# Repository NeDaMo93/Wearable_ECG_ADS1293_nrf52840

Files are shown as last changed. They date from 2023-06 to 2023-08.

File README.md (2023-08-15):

# Wearable_ECG_ADS1293_nrf52840
Software for a Functional Demonstrator of a Medical Wearable for ECG and Activity Monitoring with Wireless Communication. With ADS1293, nrf52840, LSM6DSO. Includes an Android App and Python GUI.
# Summary of the research project
This research project aims to design and develop a functional demonstrator of a portable device for long-term Electrocardiogram (ECG) measurements. The proposed device intends to address the need for continuous and non-invasive monitoring of cardiac activity over extended periods, providing valuable insights into the diagnosis and management of cardiovascular conditions.
In addition to enabling long-term Electrocardiogram (ECG) measurements, the developed wearable device will also incorporate advanced sensors to monitor body position, physical activity, and body temperature continuously. This comprehensive approach aims to provide a holistic assessment of the user's physiological status, allowing for a more thorough evaluation of their overall health. 
The primary objective of this project is to create a working prototype that can serve as a foundation for future advancements in the field. The successful development of this device will facilitate subsequent research projects, fostering innovation and further exploration of long-term ECG monitoring technologies at our institution.
Throughout the research process, various aspects, such as hardware design, signal processing algorithms, power efficiency, and user-friendliness, will be carefully considered and optimized to ensure the device's reliability and practicality. Additionally, emphasis will be placed on achieving a cost-effective solution without compromising the quality of data collected.
Ultimately, the successful completion of this project will lay the groundwork for subsequent investigations, encouraging a continuous cycle of research and development in the domain of portable long-term ECG monitoring. The findings and insights gained from this study will contribute significantly to the improvement of cardiac healthcare and enhance the quality of life for individuals with cardiovascular conditions.
# Hardware Architecture
Based on the requirements, the concept architecture and associated functions could be defined by using specific hardware, which is shown in the following figure. For the demonstrator, Nordic's nRF52840 microcontroller acts as the central element, which is available in the form of a developer board from Adafruit Feather. This board has several integrated functions, including push buttons for triggering external events, LEDs for status indication, and an energy-efficient Bluetooth module. A matching SD card module from Adafruit allows local storage of recorded data. The ADS1293 is used as the analog front end for processing ECG signals. The user's activity level and body position are detected with the help of the ST LSM6DSO IMU. Body temperature is measured by using a PT1000 sensor. The Easypack S rechargeable battery system from Varta supplies the necessary energy. Finally, the collected data is transmitted via Bluetooth to a PC and Android smartphone and displayed.

# Software Architecture
The firmware is designed to efficiently handle data acquisition from the ECG and IMU (Inertial Measurement Unit) sensors and transmit the collected data via Bluetooth Low Energy (BLE) while storing it on an SD card. The architecture is implemented using six components, including four separate threads and two interrupt Service Routines (ISRs).

# User Interfaces
## Anrdoid App
The Android application was constructed using the open-source code provided by Nordic for the Android-nRF-Blinky application. 
The Android-nRF-Blinky application, written in Kotlin, serves as an excellent introduction for developers unfamiliar with Bluetooth Low Energy (BLE) and can serve as a template for other projects.
The application uses the Android BLE Library to manage its Bluetooth connections. When the application starts, it scans for nearby BLE devices. Once a device is selected, the application connects to it and discovers its services and characteristics (using the GATT protocol). 

## Python GUI
The Python-based graphical user interface (GUI) connects the ECG device via Bluetooth Low Energy (BLE) and visualizes real-time ECG data. It also displays the patient's activity level, body temperature, heart rate and body posture. The code utilizes PyQt5 for GUI development, Matplotlib for plotting, asyncio for asynchronous tasks, Bleak for BLE communication, and biosppy for ECG signal processing.


# LBS Files
lbs.h and lbs.c must be replaced in your zephyr directory <br>
**lbs.h:**<br>
..\nrf\include\bluetooth\services<br>
**lbs.c:**<br>
..\nrf\subsys\bluetooth\services<br>

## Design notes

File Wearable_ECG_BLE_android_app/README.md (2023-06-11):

# nRF Blinky for Android

nRF Blinky is an application targeting an audience of developers who are new to 
Bluetooth Low Energy. 

The app can be easily converted to work with other devices and may act as a template app.

This very simple application contains two basic features:
* turning on a LED on a connected Bluetooth LE device,
* receiving a Button press and release events from the device.

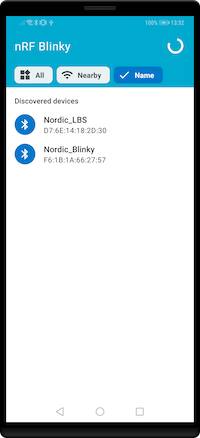
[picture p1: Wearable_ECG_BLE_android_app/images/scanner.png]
Scanner
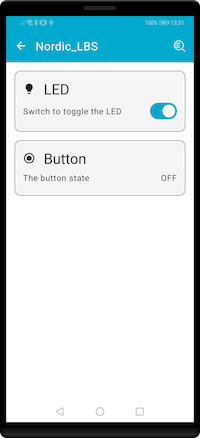
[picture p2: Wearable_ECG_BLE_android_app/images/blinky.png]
Blinky
 

It demonstrates how the `BleManager` class from 
[Android BLE Library](https://github.com/NordicSemiconductor/Android-BLE-Library/) 
library can be used from a View Model 
(see [Architecture Components](https://developer.android.com/topic/libraries/architecture/index.html)).

## Structure

The new version of nRF Blinky application has been created in Jetpack Compose.

### Dependencies

It is using the following libraries:
* [Android BLE Library](https://github.com/NordicSemiconductor/Android-BLE-Library/) - handles Bluetooth LE connectivity
* [Nordic Common Library for Android](https://github.com/NordicPlayground/Android-Common-Libraries) - theme and common UI components, e.g. scanner screen
* [nRF Logger tree for Timber](https://github.com/NordicSemiconductor/nRF-Logger-API) - logs to nRF Logger app using [Timber](https://github.com/JakeWharton/timber)
* [Android Gradle Plugins](https://github.com/NordicSemiconductor/Android-Gradle-Plugins) - set of Gradle plugins

The gradle script was written in Kotlin Script (*gradle.kts*) and is using version catalog for 
dependency management.

### Modules

The application consists of the following modules:

* **:app** - the main module, contains the application code
* **:scanner** - contains the scanner screen destination
* **:blinky:spec** - contains the Blinky device specification, e.g. [`Blinky`](https://github.com/NordicSemiconductor/Android-nRF-Blinky/blob/b23b0252fe14bd0961c1edafa973f7da2768feb9/blinky/spec/src/main/java/no/nordicsemi/android/blinky/spec/B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) API or the Service UUID
* **:blinky:ble** - contains the BLE related code, e.g. [`BlinkyManager`](https://github.com/NordicSemiconductor/Android-nRF-Blinky/blob/b23b0252fe14bd0961c1edafa973f7da2768feb9/blinky/ble/src/main/java/no/nordicsemi/android/blinky/ble/Bli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) implementation
* **:blinky:ui** - contains the UI related code, e.g. [`BlinkyScreen`](https://github.com/NordicSemiconductor/Android-nRF-Blinky/blob/b23b0252fe14bd0961c1edafa973f7da2768feb9/blinky/ui/src/main/java/no/nordicsemi/android/blinky/control/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)
  or [`BlinkyViewModel`](https://github.com/NordicSemiconductor/Android-nRF-Blinky/blob/b23b0252fe14bd0961c1edafa973f7da2768feb9/blinky/ui/src/main/java/no/nordicsemi/android/blinky/control/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) implementation

The **:blinky:ui** and **:blinky:spec** modules are transport agnostic. The Bluetooth LE transport
is set using Hilt `@Binds` dependency injection [here](https://github.com/NordicSemiconductor/Android-nRF-Blinky/blob/b23b0252fe14bd0961c1edafa973f7da2768feb9/app/src/main/java/no/nordicsemi/android/blinky/di/BlinkyModul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).

The app is based on **:navigation** module from the Nordic Common Library, which is using 
[`NavHost`](https://developer.android.com/jetpack/compose/navigation) under the hood, and adds 
type-safety to the navigation graph.

Each screen defines a `DestinationId` (with input and output types) and `NavigationDestination`, 
which declares the composable, inner navigation or a dialog target. See [`BlinkyDestination`](https://github.com/NordicSemiconductor/Android-nRF-Blinky/blob/b23b0252fe14bd0961c1edafa973f7da2768feb9/blinky/ui/src/main/java/no/nordicsemi/android/blinky/control/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) for an example.

Navigation between destinations is done using [`Navigator`](https://github.com/NordicPlayground/Android-Common-Libraries/blob/d8e60628a877eccf8592da4889cf12afdbc08e44/navigation/src/main/java/no/nordicsemi/android/common/navi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) object, 
available using Hilt form a `ViewModel`. When a new destination is selected, the input parameters 
are available from `SavedStateHandle` (see [`BlinkyModule`](https://github.com/NordicSemiconductor/Android-nRF-Blinky/blob/b23b0252fe14bd0961c1edafa973f7da2768feb9/app/src/main/java/no/nordicsemi/android/blinky/di/BlinkyModul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) class).

## Nordic LED and Button Service (LBS)

Service UUID: `00001523-1212-EFDE-1523-785FEABCD123`

A simplified proprietary service by Nordic Semiconductor, containing two characteristics:

- LED state (On/Off).
  - UUID: **`00001525-1212-EFDE-1523-785FEABCD123`**
  - Properties: **Write** or **Write Without Response**
    - Value: **`0x01`** => LED On
    - Value: **`0x00`** => LED Off

- Button state (Pressed/Released).
  - UUID: **`00001524-1212-EFDE-1523-785FEABCD123`**
  - Properties: **Notify**
    - Value: **`0x01`** => Button Pressed
    - Value: **`0x00`** => Button Released
  
For documentation for nRF5 SDK, check out 
[this link](https://infocenter.nordicsemi.com/topic/sdk_nrf5_v17.1.0/ble_sdk_app_blinky.html?cp=8_1_4_2_2_3)
and for one based on nRF Connect SDK 
[this link](https://developer.nordicsemi.com/nRF_Connect_SDK/doc/latest/nrf/samples/bluetooth/peripheral_lbs/README.html).

## Requirements

* This application depends on [Android BLE Library](https://github.com/NordicSemiconductor/Android-BLE-Library/).
* Android 4.3 or newer is required.
* Any nRF5 DK or another device is required in order to test the BLE Blinky service. The service 
  can also be emulated using nRF Connect for Android, iOS or Desktop.

## Installation and usage

Program your device with LED Button sample from nRF5 SDK (blinky sample) or nRF Connect SDK (LBS sample).

The device should appear on the scanner screen after granting required permissions.

### Required permissions

On Android 6 - 11 nRF Blinky will ask for Location Permission and Location services. 
This permission is required on Android in order to obtain Bluetooth LE scan results. The app does not
use location in any way and has no Internet permission so can be used safely.

This permission is not required from Android 12 onwards, where new 
[Bluetooth permissions](https://developer.android.com/guide/topics/connectivity/bluetooth/permissions)
were introduced. The `BLUETOOTH_SCAN` permission can now be requested with 
`usesPermissionFlags="neverForLocation"` parameter, which excludes location related data from the
scan results, making requesting location not needed anymore.# ForschungsProjekt

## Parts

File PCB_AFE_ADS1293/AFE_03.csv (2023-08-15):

Source: | C:\Users\torsten.bandel\Dropbox\KiCAD\KiCAD_Projects\AFE_03\AFE_03.kicad_sch
Date: | 13.04.2023 10:56:23
Tool: | Eeschema 7.0.1
Generator: | C:\Program Files\KiCad\7.0\bin\scripting\plugins/bom_csv_grouped_by_value_with_fp.py
Component Count: | 41
Ref | Qnty | Value | Cmp name | Footprint | Description | Vendor | DNP
C1, C12, C14, C15 | 4 | 0.1uF | C_Small | Capacitor_SMD:C_0402_1005Metric | Unpolarized capacitor, small symbol
C2 | 1 | 47uF | C_Small | Capacitor_SMD:C_1206_3216Metric | Unpolarized capacitor, small symbol
C3, C4 | 2 | 10uF | C_Small | Capacitor_SMD:C_0805_2012Metric | Unpolarized capacitor, small symbol
C9 | 1 | 0.1uF | C_Small | Capacitor_SMD:C_0402_1005Metric_Pad0.74x0.62mm_HandSolder | Unpolarized capacitor, small symbol
C10, C11 | 2 | 22pF | C_Small | Capacitor_SMD:C_0402_1005Metric | Unpolarized capacitor, small symbol
C13 | 1 | 1nF | C_Small | Capacitor_SMD:C_0603_1608Metric | Unpolarized capacitor, small symbol
C16 | 1 | 0.1uF | C_Small | Capacitor_SMD:C_0603_1608Metric | Unpolarized capacitor, small symbol
IC1 | 1 | TPS61222DCK | TPS61222DCK | TPS61222DCK:DCK_R-PDSO-G6
J1 | 1 | Conn_01x03_Socket | Conn_01x03_Socket | Connector_JST:JST_XH_B3B-XH-A_1x03_P2.50mm_Vertical | Generic connector, single row, 01x03, script generated
J2, J3 | 2 | Conn_01x12 | Conn_01x12 | Connector_PinHeader_2.54mm:PinHeader_1x12_P2.54mm_Vertical | Generic connector, single row, 01x12, script generated (kicad-library-utils/schlib/autogen/connector/)
JP1 | 1 | SolderJumper_3_Open | SolderJumper_3_Open | Jumper:SolderJumper-3_P1.3mm_Open_RoundedPad1.0x1.5mm | Solder Jumper, 3-pole, open
L1 | 1 | EPL3015-472MLB | EPL3015-472MLB | EPL3015-472MLB:IND_EPL3015-472MLB
R1, R17, R18, R27, R28 | 5 | 1.0M | R_Small | Resistor_SMD:R_0402_1005Metric | Resistor, small symbol
R2 | 1 | 200k | R_Small | Resistor_SMD:R_0402_1005Metric | Resistor, small symbol
R3, R8, R19, R20, R21, R22, R23 | 7 | 0 | R_Small | Resistor_SMD:R_0402_1005Metric | Resistor, small symbol
R4, R6, R7, R25, R26 | 5 | 51 | R_Small | Resistor_SMD:R_0402_1005Metric | Resistor, small symbol
R5 | 1 | 10k | R_Small | Resistor_SMD:R_0402_1005Metric | Resistor, small symbol
R9 | 1 | 10M | R_Small | Resistor_SMD:R_0402_1005Metric | Resistor, small symbol
SW2 | 1 | SW_SPST | SW_SPST | Button_Switch_SMD:SW_Push_1P1T_NO_6x6mm_H9.5mm | Single Pole Single Throw (SPST) switch
U2 | 1 | ADS1293CISQ/NOPB | ADS1293CISQ{slash}NOPB | ADS1293CISQ_NOPB:QFN50P500X500X80-29N
Y2 | 1 | Crystal_Small | Crystal_Small | Crystal:Crystal_SMD_HC49-SD | Two pin crystal, small symbol

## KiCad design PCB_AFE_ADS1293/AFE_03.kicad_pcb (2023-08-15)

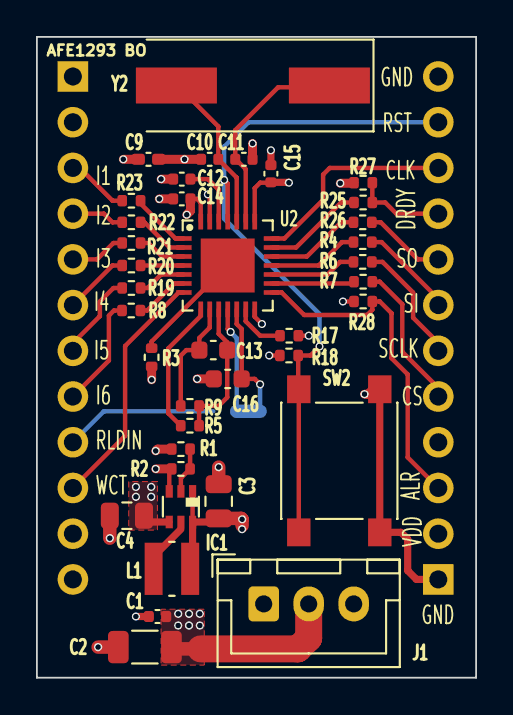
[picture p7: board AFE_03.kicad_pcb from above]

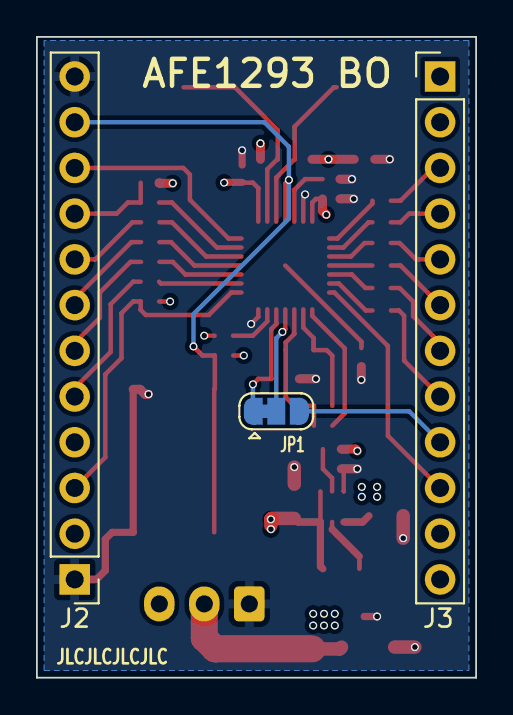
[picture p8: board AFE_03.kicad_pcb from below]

Board: 4 copper layers, 24.4 x 35.6 mm, 41 parts (3 on the bottom side), 41 nets.

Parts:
C1, C12, C14, C15: 0.1uF; C_0402_1005Metric
C2: 47uF; C_1206_3216Metric
C3, C4: 10uF; C_0805_2012Metric
C9: 0.1uF; C_0402_1005Metric_Pad0.74x0.62mm_HandSolder
C10, C11: 22pF; C_0402_1005Metric
C13: 1nF; C_0603_1608Metric
C16: 0.1uF; C_0603_1608Metric
IC1: TPS61222DCK; DCK_R-PDSO-G6
J1: Conn_01x03_Socket; JST_XH_B3B-XH-A_1x03_P2.50mm_Vertical
J2, J3: Conn_01x12; PinHeader_1x12_P2.54mm_Vertical
JP1: SolderJumper_3_Open; SolderJumper-3_P1.3mm_Open_RoundedPad1.0x1.5mm
L1: EPL3015-472MLB; IND_EPL3015-472MLB
R1, R17, R18, R27, R28: 1.0M; R_0402_1005Metric
R2: 200k; R_0402_1005Metric
R3, R8, R19, R20, R21, R22, R23: 0; R_0402_1005Metric
R4, R6, R7, R25, R26: 51; R_0402_1005Metric
R5: 10k; R_0402_1005Metric
R9: 10M; R_0402_1005Metric
SW2: SW_SPST; SW_Push_1P1T_NO_6x6mm_H9.5mm
U2: ADS1293CISQ/NOPB; QFN50P500X500X80-29N
Y2: Crystal_Small; Crystal_SMD_HC49-SD

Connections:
ALARMB: J2.3, R28.1, U2.15 (ALARMB)
CLK: J2.10, U2.21 (CLK)
CMOUT: R5.1, U2.8 (CMOUT)
CS: J2.5, R7.2
DRDYB: J2.9, R25.2, R27.1
GND: C1.2, C2.2, C3.2, C4.2, C9.2, C12.2, C14.2, C15.2, C16.2, IC1.3 (GND), J1.1, J2.1, J2.12, R2.2, R3.1, SW2.1 (A), U2.14 (VSSIO), U2.27 (VSS)
IN1: J3.3, R23.1
IN2: J3.4, R22.1
IN3: J3.5, R21.1
IN4: J3.6, R20.1
IN5: J3.7, R19.1
IN6: J3.8, R8.1
MISO: J2.8, R26.2
MOSI: J2.7, R4.2
unnamed: IC1.2 (FB), R1.2, R2.1
unnamed: IC1.5 (L), L1.1
unnamed: C16.1, JP1.1 (A), JP1.2 (C), U2.11 (RLDIN), U2.12 (RLDREF)
unnamed: R7.1, U2.16 (CSB)
unnamed: C12.1, U2.26 (CVREF)
unnamed: R3.2, U2.29 (DAP)
unnamed: R25.1, U2.20 (DRDYB)
unnamed: R23.2, U2.1 (IN1)
unnamed: R22.2, U2.2 (IN2)
unnamed: R21.2, U2.3 (IN3)
unnamed: R20.2, U2.4 (IN4)
unnamed: R19.2, U2.5 (IN5)
unnamed: R8.2, U2.6 (IN6)
unnamed: R6.1, U2.17 (SCLK)
unnamed: R4.1, U2.18 (SDI)
unnamed: R26.1, U2.19 (SDO)
unnamed: R17.2, U2.13 (SYNCB)
unnamed: C11.2, U2.23 (XTAL1), Y2.1
unnamed: C10.2, U2.24 (XTAL2), Y2.2
RLDIN: J3.9, JP1.3 (B)
RLDINIV: C13.2, R5.2, R9.2, U2.10 (RLDINV)
RLDOUT: C13.1, R9.1, U2.9 (RLDOUT)
RSTB: J2.11, R18.2, SW2.2 (B), U2.25 (RSTB)
SCLK: J2.6, R6.2
VDD: C1.1, C2.1, C3.1, C15.1, IC1.1 (VIN), IC1.6 (EN), J1.2, J2.2, L1.2, R17.1, R18.1, R27.2, R28.2, U2.22 (VDDIO)
VDDA: C4.1, C9.1, C10.1, C11.1, C14.1, IC1.4 (VOUT), R1.1, U2.28 (VDD)
WCT: J3.10, U2.7 (WCT)

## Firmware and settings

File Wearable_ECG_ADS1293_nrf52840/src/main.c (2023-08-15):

/*
 * Research project 2023/2024
 */

/**************************************ZEPHYR LIB INCLUDES***********************************************/
#include <zephyr/types.h>
#include <stddef.h>
#include <string.h>
#include <errno.h>
#include <zephyr/sys/printk.h>
#include <zephyr/sys/byteorder.h>
#include <zephyr/kernel.h>
#include <zephyr/drivers/gpio.h>
#include <soc.h>
#include <zephyr/bluetooth/bluetooth.h>
#include <zephyr/bluetooth/hci.h>
#include <zephyr/bluetooth/conn.h>
#include <zephyr/bluetooth/uuid.h>
#include <zephyr/bluetooth/gatt.h>
#include <zephyr/drivers/sensor.h>
#include <math.h>
#include <stdio.h>
#include <stdbool.h>
#include <time.h>
#include <zephyr/kernel.h>
#include <zephyr/device.h>
#include <bluetooth/services/lbs.h>
#include <zephyr/settings/settings.h>
#include <dk_buttons_and_leds.h>
#include <zephyr/logging/log.h>
#include <zephyr/drivers/spi.h>  // provides access to SPI driver features
#include <zephyr/drivers/gpio.h>  // provides access to GPIO driver features
#include <hal/nrf_gpio.h>

/************************************** HEADER FILES INCLUDES ***********************************************/
#include "bluetooth_connection.h"
#include"lsm6dso.h"
#include"connexion_check.h"
#include "sd_card_flash.h"
#include"detect_activity.h"
#include"ADS1293.h"
#include"imu_trigger.h"
#include"Queue.h"
#include"temperatureSens.h"
#include "batteryManagement.h"

/************************************** THREADS SEMAPHORES ***********************************/
//Define sd-card semaphore
K_SEM_DEFINE(sd_card_sem, 1, 1); 
//Define semaphore for imu thread
K_SEM_DEFINE(imu_sem, 0, 1); 
//Define semaphore for ecg thread
K_SEM_DEFINE(ecg_sem, 0, 1); 
//Define semaphore for temperature thread
K_SEM_DEFINE(temp_sem, 0, 1); 

/************************************** DEFINE THREADS ****************************************/
K_THREAD_STACK_DEFINE(ecg_thread_stack_area, 2048);
K_THREAD_STACK_DEFINE(imu_thread_stack_area, 2048);
K_THREAD_STACK_DEFINE(temp_thread_stack_area, 2048);
struct k_thread ecg_thread_data;
struct k_thread imu_thread_data;
struct k_thread temp_thread_data;
K_MUTEX_DEFINE(sensor_data_mutex);
K_MUTEX_DEFINE(queue_data_mutex);

/************************************** GLOBALE VARIABLE  *************************************/
typedef struct {
    uint16_t channel_1_ecgVal;
    uint16_t channel_2_ecgVal;
} Ecg_values_norm;
//4232264
uint32_t offset_ecg = 4238892;
uint32_t last_interrupt_time = 0;
uint64_t last_imu_read_time = 0;
uint32_t imu_activity_buffer [4];
uint16_t temp_posture_buffer [2];
uint32_t raw_ecg_buffer[8];
uint16_t ecg_buffer[8];
Queue* imu_activity_queue = NULL; 
uint32_t body_posture;
float body_temperature;
uint32_t bodyTemp_toBe_send;
bool temperature_flag = false;
volatile bool ecg_data_sent = false;
K_MUTEX_DEFINE(ble_data_mutex);
LOG_MODULE_REGISTER(main);

// power saving for battery temp
#define POWER NRF_GPIO_PIN_MAP(0,28)
/************************************** STATIC VARIABLES **************************************/
static int lsdir(const char *path);
static FATFS fat_fs;
static int file_count = 0;
struct fs_file_t ecg_file;
struct fs_file_t imu_file;

/************************************** SD CARD MOUNTING ***************************************/
/* mounting info */
static struct fs_mount_t mp = {
	.type = FS_FATFS,
	.fs_data = &fat_fs,
};
static const char *disk_mount_pt = "/SD:";

/************************************** IMU SAMPLING FREQUENCY *********************************/
static int set_sampling_freq(const struct device *dev)
{
	int ret_gpio = 0;
	struct sensor_value odr_attr;

	/* set accel sampling frequency to 208 Hz */
	odr_attr.val1 = 208;
	odr_attr.val2 = 0;

	ret_gpio = sensor_attr_set(dev, SENSOR_CHAN_ACCEL_XYZ,
			SENSOR_ATTR_SAMPLING_FREQUENCY, &odr_attr);
	if (ret_gpio != 0) {
		printf("Cannot set sampling frequency for accelerometer.\n");
		return ret_gpio;
	}

	ret_gpio = sensor_attr_set(dev, SENSOR_CHAN_GYRO_XYZ,
			SENSOR_ATTR_SAMPLING_FREQUENCY, &odr_attr);
	if (ret_gpio != 0) {
		printf("Cannot set sampling frequency for gyro.\n");
		return ret_gpio;
	}

	return 0;
}

/************************************** SD CARD LISTDIR ************************************************/
// SD
static int lsdir(const char *path)
{
    int res;
    struct fs_dir_t dirp;
    static struct fs_dirent entry;
    int count = 0;

    fs_dir_t_init(&dirp);

    res = fs_opendir(&dirp, path);
    if (res) {
        printk("Error opening dir %s [%d]\n", path, res);
        return res;
    }

    printk("\nListing dir %s ...\n", path);
    while (1) {
        res = fs_readdir(&dirp, &entry);
        if (res || entry.name[0] == 0) {
            break;
        }

        if (entry.type != FS_DIR_ENTRY_DIR) {
            count++;
            if (count % 2 == 0) {
                file_count++;
            }
        }

        if (entry.type == FS_DIR_ENTRY_DIR) {
            printk("[DIR ] %s\n", entry.name);
        } else {
            printk("[FILE] %s (size = %zu)\n",
                entry.name, entry.size);
        }
    }

    fs_closedir(&dirp);

    return res;
}

/************************************** CALCULATE FREQUENCY  ************************************************/
double calculate_freq(uint32_t current_time)
{
	uint32_t interrupt_period;
	double frequency_hz;

	if (last_interrupt_time != 0) {
		if (current_time >= last_interrupt_time) {
			interrupt_period = current_time - last_interrupt_time;
		} else {
			// handle overflow
			interrupt_period = UINT32_MAX - last_interrupt_time + current_time;
		}

		// Convert to nanoseconds
		uint64_t interrupt_period_ns = k_cyc_to_ns_ceil64(interrupt_period);

		// Calculate frequency (Hz) = 1 / period (s)
		// The period is in nanoseconds, so we need to divide by 1e9 to convert to seconds
		double period_s = (double)interrupt_period_ns / 1e9;

		// Calculate frequency
		frequency_hz = 1.0 / period_s;

		//printf("Interrupt frequency: %.2f Hz\n", frequency_hz);
	}

	last_interrupt_time = current_time;
	return frequency_hz;

}

/************************************** ECG THREAD ************************************************/
void ecg_data_acquisition_thread(void *unused1, void *unused2, void *unused3) {
	int ecg_buffer_ind = 0;
	
    while (1) {
		
		Ecg_values_norm ecg_values_norm;
		// wait for semaphore
		k_sem_take(&ecg_sem, K_FOREVER); // the semaphore count goes down to 0

		ECG_Values ecg_values = read_ecg_values();

		ecg_values_norm.channel_1_ecgVal = ecg_values.channel_1_ecgVal - offset_ecg;
		ecg_values_norm.channel_2_ecgVal = ecg_values.channel_2_ecgVal - offset_ecg;
		///printf(", Values norm: %u, %u\n", ecg_values_norm.channel_1_ecgVal , ecg_values_norm.channel_2_ecgVal);

		//calculate frequency
		uint32_t current_time = k_cycle_get_32();
		double frequency_hz = calculate_freq(current_time);

		//fill buffer with norm. values and raw values
		ecg_buffer[ecg_buffer_ind] = ecg_values_norm.channel_1_ecgVal;
		raw_ecg_buffer[ecg_buffer_ind] = ecg_values.channel_1_ecgVal;
		ecg_buffer_ind++;
		ecg_buffer[ecg_buffer_ind] = ecg_values_norm.channel_2_ecgVal;
		raw_ecg_buffer[ecg_buffer_ind] = ecg_values.channel_2_ecgVal;
		ecg_buffer_ind = (ecg_buffer_ind+1)%8;

		// wake up IMU thread to synchronize READ DATA 
		k_sem_give(&imu_sem);

		if ( ecg_buffer_ind == 0){
			
			//BLE send ECG packet, is blocked to avoid BLE conflicts, could also work with threads flags
			k_mutex_lock(&ble_data_mutex, K_FOREVER);
		    send_ECG_Packet_Data(ecg_buffer, sizeof(ecg_buffer));
			k_mutex_unlock(&ble_data_mutex);

			//flash data to sd card
			k_sem_take(&sd_card_sem, K_FOREVER); // Take the semaphore

			flash_ecg_data_to_sd_card(&ecg_file, raw_ecg_buffer);
			k_sem_give(&sd_card_sem); // Give the semaphore
			
			// Clear the buffer
            for (int i = 0; i < 8; i++) {
                ecg_buffer[i] = 0;
            }

		}
    }
}

/************************************** IMU THREAD ************************************************/

void imu_data_acquisition_thread(void *unused1, void *unused2, void *unused3) {

	int imu_activity_buffer_ind = 0;
	uint32_t last_fetch_time = 0;
	uint32_t current_t;
    while (1) {
		
		/* Wait until semaphore is called */
        k_sem_take(&imu_sem, K_FOREVER); // the semaphore count goes down to 0
		
		//calculate the mean value of the values saved on the queue, and then dequeue the queue to liberate space

		uint32_t mean_imu_val = calculateMean(imu_activity_queue);

		imu_activity_buffer[imu_activity_buffer_ind] = mean_imu_val;
		imu_activity_buffer_ind = (imu_activity_buffer_ind+1)%4;
		
		//dequeue the queue
		k_mutex_lock(&queue_data_mutex, K_FOREVER);
		emptyQueue(imu_activity_queue);
		k_mutex_unlock(&queue_data_mutex);

		if (imu_activity_buffer_ind == 0){
		current_t= k_uptime_get();
		//read temperature value
		bodyTemp_toBe_send = body_temperature *(100); //covert float to uint32_t
			
		//fill temp_posture_buffer
		temp_posture_buffer[0] = bodyTemp_toBe_send;
		temp_posture_buffer[1] = body_posture;

		printf("Temperature = %u \n",temp_posture_buffer[0] );
		
		k_mutex_lock(&ble_data_mutex, K_FOREVER);
		send_temp_IMU_Packet_Data(imu_activity_buffer, sizeof(imu_activity_buffer));
		k_mutex_unlock(&ble_data_mutex);

		//BLE send Temperature and body-posture packet
		
		if (current_t - last_fetch_time >= 3500) //3500 is adjustable, to avoid sending 3 packet simultaneously 
		{
		k_sem_give(&temp_sem); //give semaphore to read temperature values
		send_temperatur_body_posture_Packet(temp_posture_buffer, sizeof(temp_posture_buffer));
		last_fetch_time = current_t;
     	}
	
		//write to sd card

		k_sem_take(&sd_card_sem, K_FOREVER); // Take the semaphore to write to sd card
		k_mutex_lock(&sensor_data_mutex, K_FOREVER);
		flash_imu_data_to_sd_card(&imu_file, imu_activity_buffer);
		k_mutex_unlock(&sensor_data_mutex);
		k_sem_give(&sd_card_sem); 

		// Clear the buffer
		for (int i = 0; i < 4; i++) { 
			imu_activity_buffer[i] = 0;
		}
		}
    }
}

/************************************** TEMP THREAD ************************************************/
void temp_data_acquisition_thread()
{
	while(1)
	{
		k_sem_take(&temp_sem, K_FOREVER); // the semaphore count goes down to 0
		body_temperature = get_bodyTemperature();
		nrf_gpio_pin_set(POWER);
		get_battery_info();
		nrf_gpio_pin_clear(POWER);
	}

}

/************************************** DETECT SD CARD ************************************************/
void mount_sd_card()
{
	/* sd card detected? */
	do {
		static const char *disk_pdrv = "SD";
		uint64_t memory_size_mb;
		uint32_t block_count;
		uint32_t block_size;

		if (disk_access_init(disk_pdrv) != 0) {
			LOG_ERR("Storage init ERROR!");
			break;
		}

		if (disk_access_ioctl(disk_pdrv,
				DISK_IOCTL_GET_SECTOR_COUNT, &block_count)) {
			LOG_ERR("Unable to get sector count");
			break;
		}
		LOG_INF("Block count %u", block_count);

		if (disk_access_ioctl(disk_pdrv,
				DISK_IOCTL_GET_SECTOR_SIZE, &block_size)) {
			LOG_ERR("Unable to get sector size");
			break;
		}
		printk("Sector size %u\n", block_size);

		memory_size_mb = (uint64_t)block_count * block_size;
		printk("Memory Size(MB) %u\n", (uint32_t)(memory_size_mb >> 20));
	} while (0);

	mp.mnt_point = disk_mount_pt;
	int res = fs_mount(&mp);

	if (res == FR_OK) {
		printk("Disk mounted.\n");
		lsdir(disk_mount_pt);
	} else {
		printk("Error mounting disk.\n");
	}
}

/************************************** CREAT IMU/ECG/Temp THREADS ************************************************/
void start_ecg_data_acquisition_thread(void) {
    k_thread_create(&ecg_thread_data, ecg_thread_stack_area, K_THREAD_STACK_SIZEOF(ecg_thread_stack_area), 
                    ecg_data_acquisition_thread, NULL, NULL, NULL, 1, 0, K_NO_WAIT);
}

void start_imu_data_acquisition_thread(void) {
    k_thread_create(&imu_thread_data, imu_thread_stack_area, K_THREAD_STACK_SIZEOF(imu_thread_stack_area), 
                    imu_data_acquisition_thread, NULL, NULL, NULL, 2, 0, K_NO_WAIT);
}

void start_temperature_data_acquisition_thread(void) {
    k_thread_create(&temp_thread_data, temp_thread_stack_area, K_THREAD_STACK_SIZEOF(temp_thread_stack_area), 
                    temp_data_acquisition_thread, NULL, NULL, NULL, 3, 0, K_NO_WAIT);
}

/************************************** IMU TRIGGER/POOLING MODE  ************************************************/

#ifdef CONFIG_LSM6DSO_TRIGGER
static void trigger_handler(const struct device *dev,
			    const struct sensor_trigger *trig)
{
	uint32_t mag_acc_val;
	MagAccData output_imu_sensor = fetch_and_display_IMU_val(dev);
	mag_acc_val = output_imu_sensor.mag_accelerometer;
	body_posture = output_imu_sensor.body_posture;
	k_mutex_lock(&queue_data_mutex, K_FOREVER);
    enQueue(imu_activity_queue, mag_acc_val);
	k_mutex_unlock(&queue_data_mutex);
	
}

static void test_trigger_mode(const struct device *dev)
{
	struct sensor_trigger trig;

	if (set_sampling_freq(dev) != 0)
		return;

	trig.type = SENSOR_TRIG_DATA_READY;
	trig.chan = SENSOR_CHAN_ACCEL_XYZ;

	if (sensor_trigger_set(dev, &trig, trigger_handler) != 0) {
		printf("Could not set sensor type and channel\n");
		return;
	}
}

#else
static void test_polling_mode(const struct device *dev)
{
	if (set_sampling_freq(dev) != 0) {
		return;
	}

	while (1) {
		fetch_and_display_IMU_val(dev);
		k_sleep(K_MSEC(1000));
	}
}
#endif

/************************************** IMU POOLING MODE  ************************************************/
//POOLING MODE
static void test_polling_mode(const struct device *dev)
{

	if (!device_is_ready(dev)) {
		printf("%s: device not ready.\n", dev->name);
		return;
	}
	printf("Testing LSM6DSO sensor in polling mode.\n\n");

	if (set_sampling_freq(dev) != 0) {
		return;
	}

	while (1) {
	
	uint32_t mag_acc_val;
	MagAccData output_imu_sensor = fetch_and_display_IMU_val(dev);
	mag_acc_val = output_imu_sensor.mag_accelerometer;
	k_mutex_lock(&queue_data_mutex, K_FOREVER);
    enQueue(imu_activity_queue, mag_acc_val);
	k_mutex_unlock(&queue_data_mutex);

	}
}

/************************************** ADS1293 INTERRUPT CALLBACK **********************************/
void ecg_data_callback(const struct device *dev, struct gpio_callback *cb, uint32_t pins)
{
    ads1293_interrupt = true;
	
	k_sem_give(&ecg_sem); 
}

void main(void)

{	/************************************** LOCAL VARIABLES ******************************************/
	int count_temp_sens = 0;
	/************************************** INITIALIZE IMU SENSOR  **********************************/
	//Initialize IMU sensor
	const struct device *const dev = DEVICE_DT_GET_ONE(st_lsm6dso);
	if (!device_is_ready(dev)) {
		printf("%s: device not ready.\n", dev->name);
		return;
	}
	printf("Testing LSM6DSO sensor in polling mode.\n\n");

	if (set_sampling_freq(dev) != 0) {
		return;
	}
	test_trigger_mode(dev);

	/************************************** INITIALIZE Temperatur SENSOR  ****************************/
	temp_sens_initialization();
	/************************************** SPI INIT ************************************************/
	//check SPI connexion
	ads1293_SPI_init();

	/************************************** GPIO INIT ************************************************/
	//Initialize GPIO Interrupt pin for ecg data
	GPIOinterrupt_init();

	/************************************** Battery Management Setup ******************************************/
	// setup battery management
	battery_management_initialization();
	nrf_gpio_cfg_output(POWER);

	/************************************** SD CARD MOUNTING ******************************************/
	//SD Card mounting
	mount_sd_card();

	/************************************** OPENNING IMU/ECG.CSV FILES **********************************/
	//Opening ECG file
	char *ecg_file_name = generate_file_name(file_count, "ECG");
	int ret_file_ecg;
	ret_file_ecg = fs_open(&ecg_file, ecg_file_name, FS_O_WRITE | FS_O_CREATE | FS_O_APPEND);
	if (ret_file_ecg < 0) {
		printk("Error opening ecg_file: %d\n", ret_file_ecg);
		return;
	}
	printk("succeess to open ecg_file %s\n",ecg_file_name );

	//Opening IMU file
	char *imu_file_name = generate_file_name(file_count, "IMU");
	int ret_file;
	ret_file = fs_open(&imu_file, imu_file_name, FS_O_WRITE | FS_O_CREATE | FS_O_APPEND);
	if (ret_file < 0) {
		printk("Error opening imu_file: %d\n", ret_file);
		return;
	}
	printk("succeess to open imu_file %s\n",imu_file_name );

	/************************************** CREATE IMU QUEUE ************************************************/
	imu_activity_queue = createQueue();

	/************************************** START IMU THREAD************************************************/
	//start imu thread
	start_imu_data_acquisition_thread();

	/************************************** START ECG THREAD ************************************************/
	//Start ecg thread
	start_ecg_data_acquisition_thread();

	/************************************** START TEMPERATURE THREAD ************************************************/
	//Start tempearture thread
	start_temperature_data_acquisition_thread();

	/************************************** BLUETOOTH INIT ************************************************/
	//Bluetooth connection
	Bluetooth_init();

}

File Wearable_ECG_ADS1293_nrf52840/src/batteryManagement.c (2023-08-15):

#include <zephyr/kernel.h>
#include <zephyr/device.h>
#include <zephyr/devicetree.h>
#include <zephyr/drivers/gpio.h>
#include <hal/nrf_gpio.h>
#include <zephyr/drivers/adc.h>
#include <zephyr/logging/log.h>
#include <stdio.h>

#define LED_BLUE NRF_GPIO_PIN_MAP(1,10)
#define LED_RED NRF_GPIO_PIN_MAP(1,15)



int ntc; 						// NTC-Resistor of Varta Easypack S
float batt_temp;
bool alarm, batt, temp, volt;

/************************************** BATTERY VOLTAGE MESSUREMENT ***********************************************/
#define BATT_ADC_NODE DT_NODELABEL(adc)
static const struct device *adc_dev = DEVICE_DT_GET(BATT_ADC_NODE);

#define ADC_RESOLUTION			10
#define BATT_ADC_CHANNEL		5
#define BATT_ADC_PORT			SAADC_CH_PSELP_PSELP_AnalogInput5
#define ADC_REFERENCE			ADC_REF_INTERNAL
#define ADC_GAIN				ADC_GAIN_1_6

struct adc_channel_cfg batt_chl_cfg = {
    .channel_id = BATT_ADC_CHANNEL,
    .gain = ADC_GAIN,
    .reference = ADC_REFERENCE,
#ifdef CONFIG_ADC_NRFX_SAADC
	.input_positive = BATT_ADC_PORT
#endif
};

int16_t batt_buffer[1];

const struct adc_sequence batt_sequence = {
	.channels    = BIT(BATT_ADC_CHANNEL),
	.buffer      = &batt_buffer,
	.buffer_size = sizeof(batt_buffer),
	.resolution  = ADC_RESOLUTION,
};

/************************************** BATTERY TEMPERATURE MESSUREMENT ***********************************************/
#define NTC_ADC_NODE DT_NODELABEL(adc)
static const struct device *adc_dev1 = DEVICE_DT_GET(NTC_ADC_NODE);

#define NTC_ADC_CHANNEL		0
#define NTC_ADC_PORT		SAADC_CH_PSELP_PSELP_AnalogInput0


struct adc_channel_cfg ntc_chl_cfg = {
    .channel_id = NTC_ADC_CHANNEL,
    .gain = ADC_GAIN,
    .reference = ADC_REFERENCE,
#ifdef CONFIG_ADC_NRFX_SAADC
	.input_positive = NTC_ADC_PORT
#endif
};

int16_t ntc_buffer[1];

const struct adc_sequence ntc_sequence = {
	.channels    = BIT(NTC_ADC_CHANNEL),
	.buffer      = &ntc_buffer,
	.buffer_size = sizeof(ntc_buffer),
	.resolution  = ADC_RESOLUTION,
};

void battery_management_initialization()
{
	nrf_gpio_cfg_output(LED_BLUE);
	nrf_gpio_cfg_output(LED_RED);



/******** BATTERY VOLTAGE MESSUREMENT ***************************************************/
	int err_batt;
	if (!device_is_ready(adc_dev)){
		printk("adc_dev not ready!\n");
		return;
	}

	err_batt = adc_channel_setup(adc_dev, &batt_chl_cfg);
	if (err_batt != 0) {
		printk("Setting up of the ADC channel failed with code %d", err_batt);
		return;
	}

/******* BATTERY TEMPERATURE MESSUREMENT ***********************************************/
	int err_ntc;
	if (!device_is_ready(adc_dev1)){
		printk("adc_dev not ready!\n");
		return;
	}

	err_ntc = adc_channel_setup(adc_dev1, &ntc_chl_cfg);
	if (err_ntc != 0) {
		printk("Setting up of the ADC channel failed with code %d", err_ntc);
		return;
	}
	printk("Battery initialized successful\n");
}

void get_battery_info()
{	
	int err_batt;
	int err_ntc;
	err_batt = adc_read(adc_dev, &batt_sequence);
	if (err_batt != 0) {
		printk("BatterieVoltage reading failed with code %d", err_batt);
		return;
	}

	err_ntc = adc_read(adc_dev1, &ntc_sequence);
	if (err_ntc != 0) {
		printk("Temperature reading failed with code %d", err_ntc);
		return;
	}
	int32_t mv_ntc = 0;
	int32_t mv_batt;
	int32_t adc_vref;
	int32_t adc_vref1;
	uint16_t count = 0;

	adc_vref = adc_ref_internal(adc_dev);
	adc_vref1 = adc_ref_internal(adc_dev1);


		mv_batt = batt_buffer[0];
		adc_raw_to_millivolts(adc_vref, ADC_GAIN, ADC_RESOLUTION, &mv_batt);

		mv_batt = mv_batt * 2 - 40;

		mv_ntc = ntc_buffer[0]; 
		adc_raw_to_millivolts(adc_vref1, ADC_GAIN, ADC_RESOLUTION, &mv_ntc);
	
		// nicht zwingend notwendig!!
		// if (mv_batt > 3460){
		// 	if (mv_ntc != 3260){
		// 		ntc = 40 + 750*mv_ntc/(3260-mv_ntc);
		// 	} else {
		// 		ntc = 40 + 750*mv_ntc;
		// 	}
		// 	//batt_temp = ((mv_ntc-(3260 / 1.264))/(-29.04));
		// } else{
		// 	if (mv_ntc != (mv_batt-200)){
		// 		ntc = 40 + 750*mv_ntc/((mv_batt-200)-mv_ntc);
		// 	} else {
		// 		ntc = 40 + 750*mv_ntc;
		// 	}
		// 	batt_temp = ((mv_ntc-((mv_batt-200) / 1.264))/(-29.04));
		// }

		volt = (mv_batt < 3700);
		batt = (mv_ntc < 3100);		// checking if Battery is inserted

		//if (count == 4){
			char buffer[10];
			int len = snprintf(buffer, sizeof(buffer), "%.1f", batt_temp);
			//printk("%d)", count)
			if (batt){
				// printk("Temp: %s;	mv_ntc: %d	ntc: %dOhm;	mv_batt: %d\n", buffer, mv_ntc, ntc, mv_batt);
			} else {
				printk("no Battery insert!	");
				//printk("Temp: %s;	ntv_mV: %d	ntc: %dOhm;	Volt: %d", buffer, mv_ntc, ntc, mv_batt);
				printk("\n");
			}


		temp = ((mv_ntc >= 2219 || mv_ntc <= 1261));
		alarm = ((mv_ntc > 2507 || mv_ntc < 1159 || mv_batt < 3500));




	if (!volt && !temp && !alarm){
		nrf_gpio_pin_toggle(LED_BLUE);
		k_msleep(100);
		nrf_gpio_pin_toggle(LED_BLUE);
		k_msleep(100);
		nrf_gpio_pin_toggle(LED_BLUE);
		nrf_gpio_pin_clear(LED_RED);
	} else if ((volt || temp) && !alarm){
		nrf_gpio_pin_clear(LED_BLUE);
		nrf_gpio_pin_toggle(LED_RED);
	} else if (alarm){
		nrf_gpio_pin_set(LED_RED);
		nrf_gpio_pin_clear(LED_BLUE);
	}

	nrf_gpio_pin_clear(LED_BLUE);
	if (!alarm){
		nrf_gpio_pin_clear(LED_RED);
	}

}

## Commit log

2023-08-15 added battery management
2023-08-15 Added PCB files
    [ADS1293.kicad_sch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]
